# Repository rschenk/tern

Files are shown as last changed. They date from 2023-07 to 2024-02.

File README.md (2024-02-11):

# Tern

Terns are small white seabirds that can hover, but it's also a 30-key keyboard based on the [Hummingbird](https://github.com/PJE66/hummingbird)! Differences from the Hummigbird:

* Hot swappable
* Spaced for Chosfox CFX keycaps (tighter than normal choc spacing)
* Pinky keys are dropped down
* Thumbs are more reachy

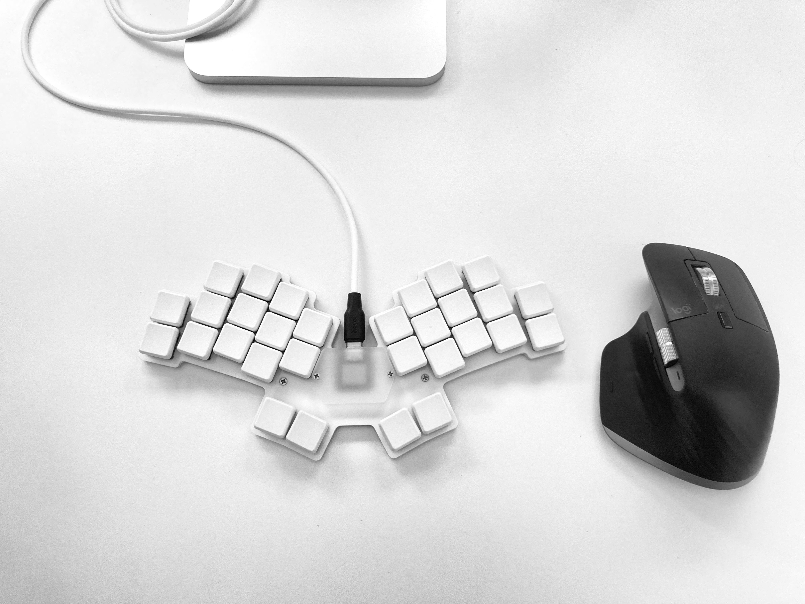
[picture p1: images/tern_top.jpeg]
tern_top


I much prefer reachy thumbs vs tucky thumbs. Years of wiping out on skateboards means my right thumb doesn’t really make that tucking motion anymore.

The other deviation from the hummingbird is that I’m using the upper pinky key as my homerow. I’m using my pinky column as home and bottom rows, not top and home rows like the hummingbird does. Cognitively I like the hummingbird’s solution better, but after cutting a stack of cardboard prototypes, I just had to admit to myself that my pinky does not enjoy extending upwards.

## Case

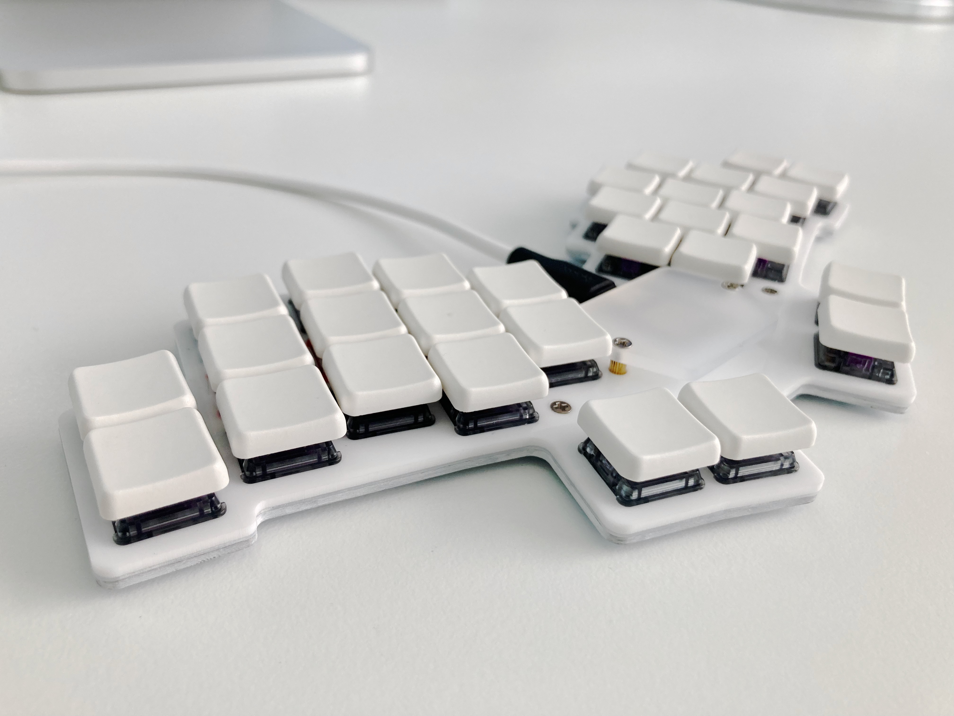
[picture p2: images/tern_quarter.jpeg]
tern_quarter


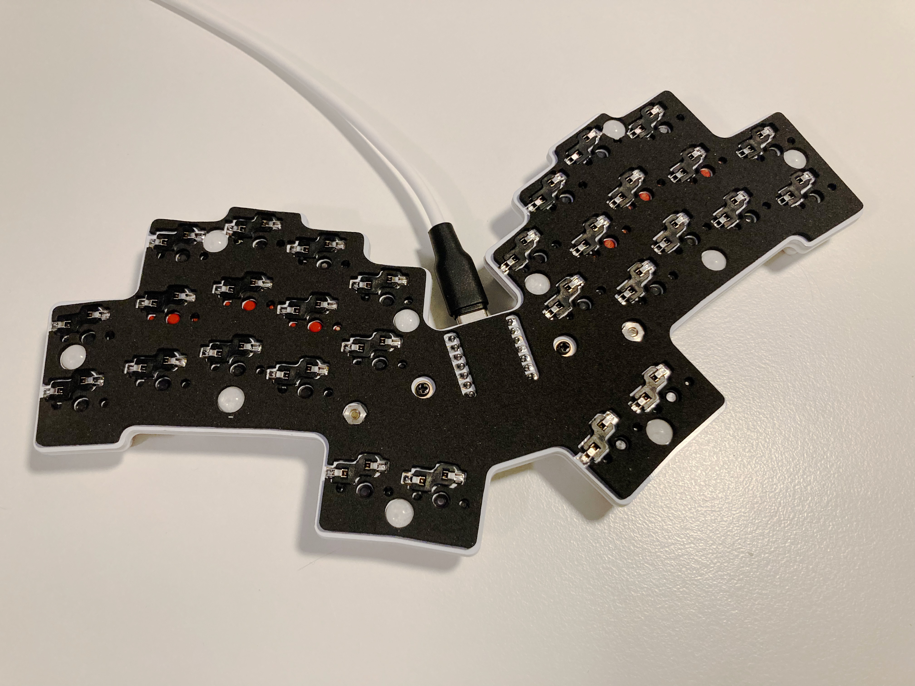
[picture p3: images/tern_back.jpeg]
tern_back


There are laser cutting files for a case in `case`. The switch plate is made from 1/16" acrylic, and there is a 0.6mm silicone gasket sitting between it and the PCB. I don't actually think the switchplate does anything functional but it looks more finished. There is a file for cutting a sheet of self-adhesive foam for the back which really helps to dampen the sound. I used 1mm sticky backed EVA. 

## Firmware

This uses an identical matrix to the Hummingbird, so you can just lie to your firmware and tell it that it's a Hummingbird. As I mentioned, though, since I dropped the pinkies and use them as home-bottom, using the stock Hummingbird config will make your keymap look a bit strange. I've included a config for ZMK in `firmware/zmk` that tweaks the matrix mapping to allow your keymap to reflect the actual position of the keys.

## Build Guide

[Build guide and bill of materials are here](docs/build_guide.md)

## Want Sculpted Keycaps?

I designed this board for Chosfox CFX keycaps, which are 1mm narrower than standard Choc keycaps such as MBK. The CFX keycaps are great if you like flat uniform keycaps, but if you want something sculpted, I forked the Chicago Steno repo and resized them to fit the CFX spacing. They are also sprued so you can 3D print them from someplace like JLC. See [rschenk/cfx_chicago_stenographer](https://github.com/rschenk/cfx_chicago_stenographer)

## Thanks

* [Hummingbird](https://github.com/PJE66/hummingbird) for the original idea and matrix
* [Rufous](https://github.com/jcmkk3/trochilidae) for the basis of the Ergogen config and routing

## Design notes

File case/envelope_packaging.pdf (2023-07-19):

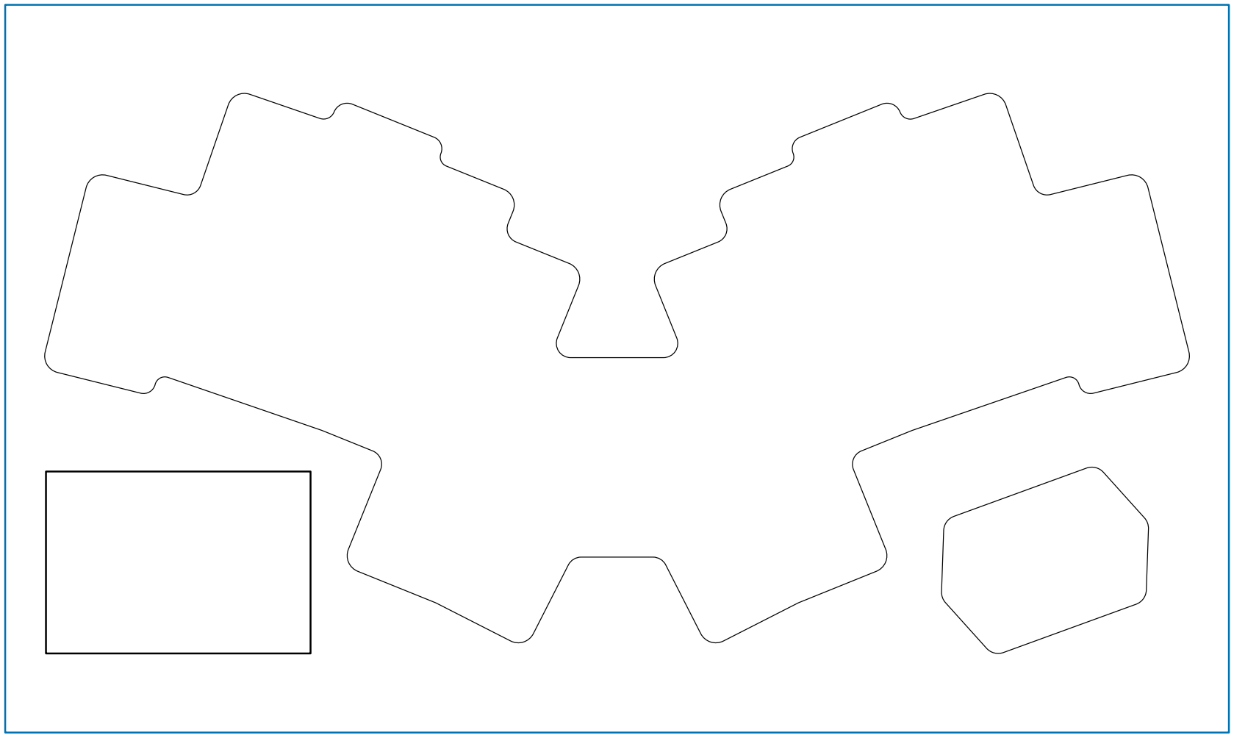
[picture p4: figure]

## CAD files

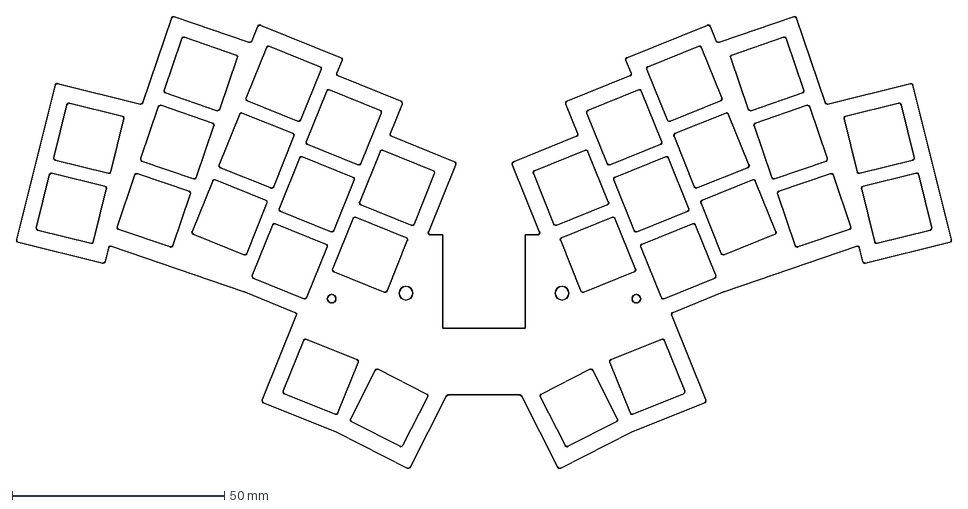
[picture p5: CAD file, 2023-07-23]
ergogen/output/outlines/switchplate.dxf
220.5 x 106.6 mm

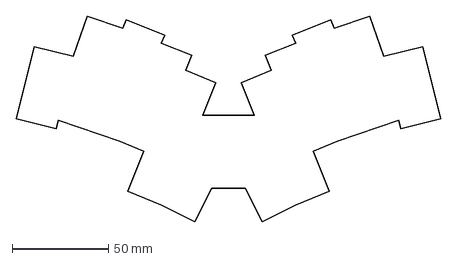
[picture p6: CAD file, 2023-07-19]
ergogen/output/outlines/panel.dxf
220.6 x 106.8 mm

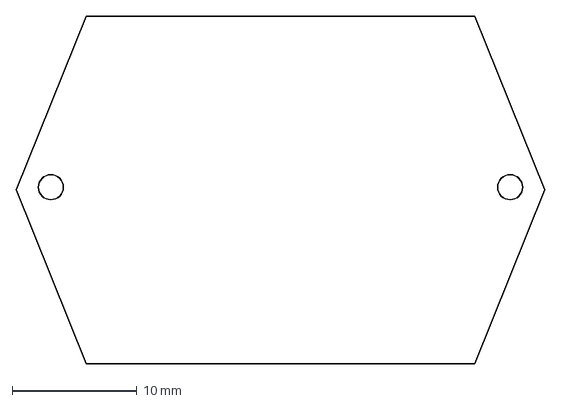
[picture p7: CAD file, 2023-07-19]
ergogen/output/outlines/mcu_cover.dxf
42.4 x 27.8 mm

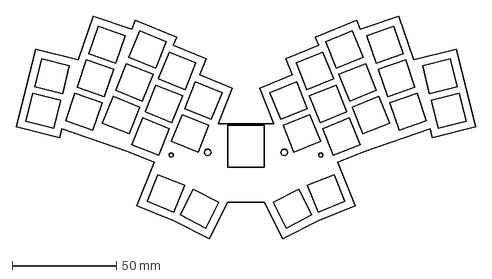
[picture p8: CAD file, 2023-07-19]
ergogen/output/outlines/demo_switches.dxf
220.6 x 106.8 mm

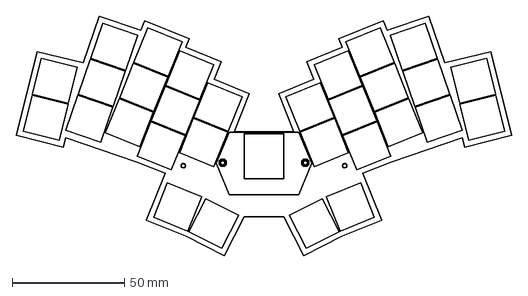
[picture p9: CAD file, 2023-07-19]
ergogen/output/outlines/demo_keycaps.dxf
220.6 x 106.8 mm

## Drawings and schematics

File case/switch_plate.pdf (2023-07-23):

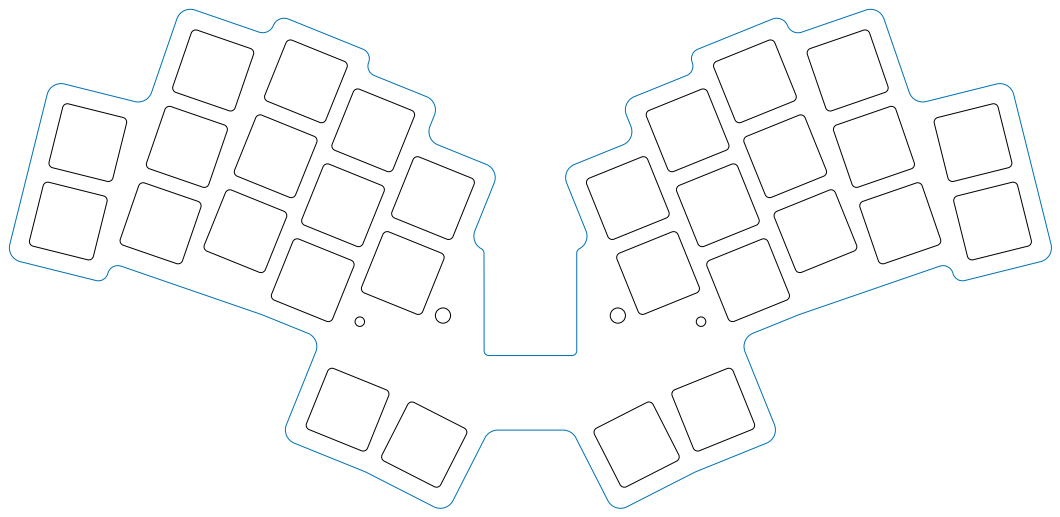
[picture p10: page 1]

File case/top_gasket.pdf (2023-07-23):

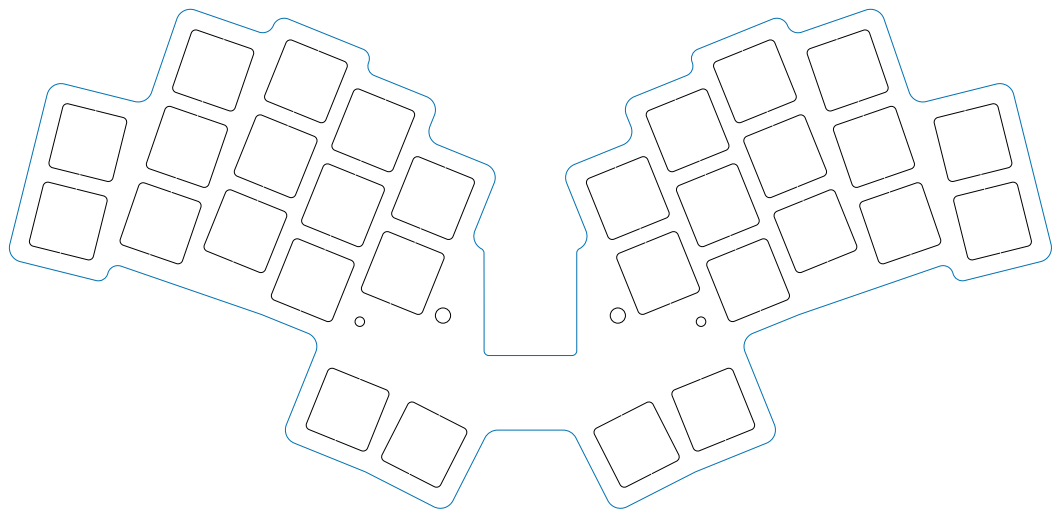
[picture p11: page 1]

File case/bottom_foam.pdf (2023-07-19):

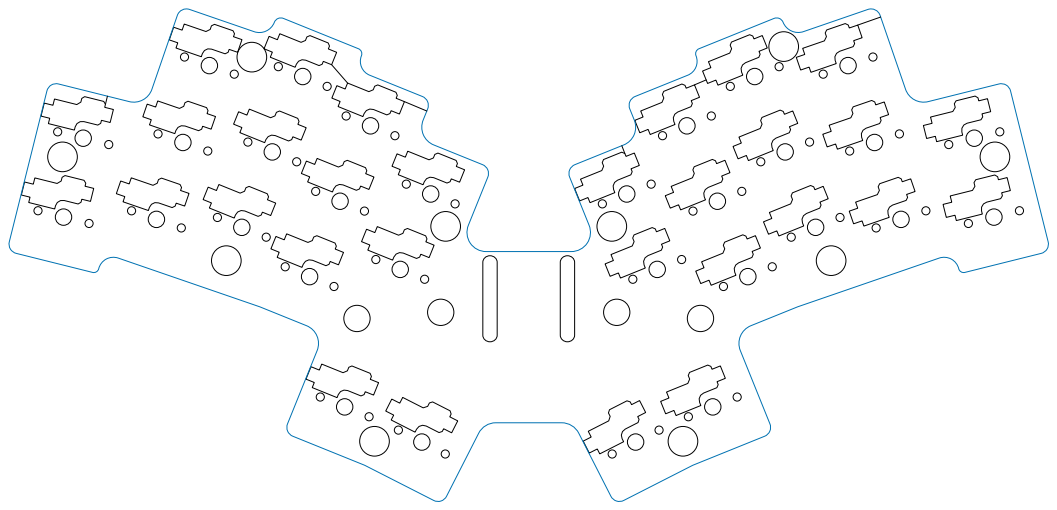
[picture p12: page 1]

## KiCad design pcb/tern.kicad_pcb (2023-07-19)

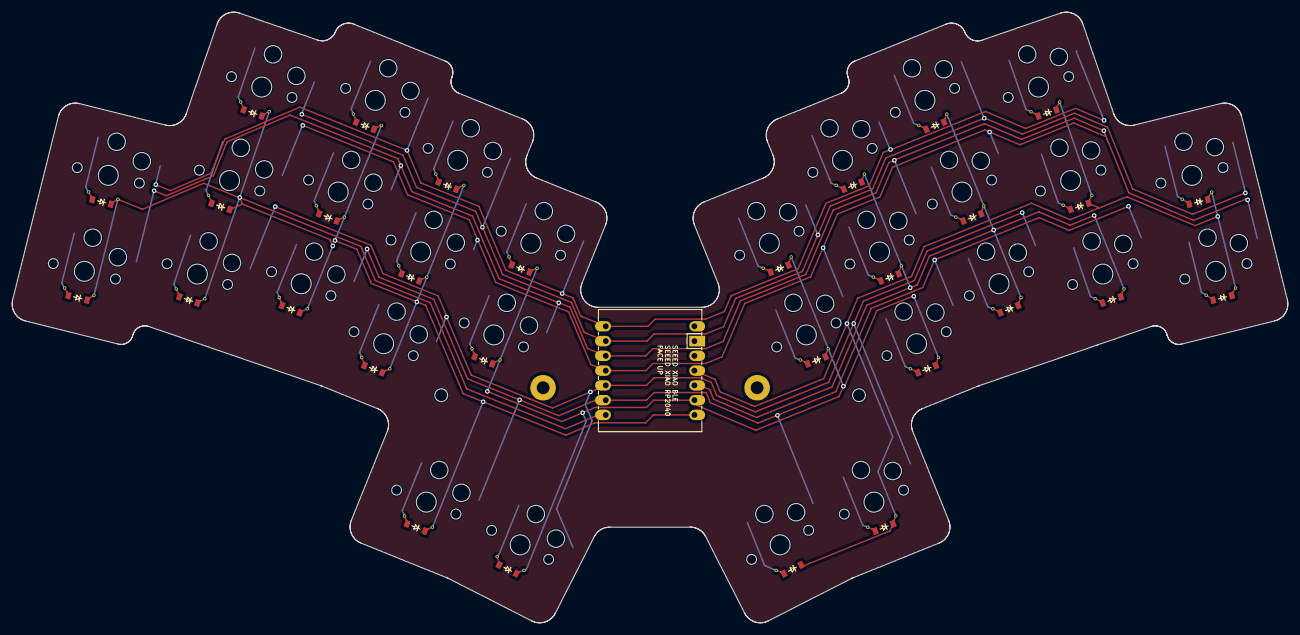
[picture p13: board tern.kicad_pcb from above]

Board: 2 copper layers, 219.3 x 105.0 mm, 95 parts (0 on the bottom side), 41 nets.

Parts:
D1, D2, D3, D4, D5, D6, D7, D8, D9, D10, D11, D12, D13, D14, D15, D16, D17, D18, D19, D20, D21, D22, D23, D24, D25, D26, D27, D28, D29, D30: ComboDiode
MCU1: xiao-ble
PAD1, PAD2: MountingHole_2.2mm_M2
PAD3, PAD4: MountingHole_2.2mm_M2_Pad
S1, S2, S3, S4, S5, S6, S7, S8, S9, S10, S11, S12, S13, S14, S15, S16, S17, S18, S19, S20, S21, S22, S23, S24, S25, S26, S27, S28, S29, S30: PG1350
SB1, SB2, SB3, SB4, SB5, SB6, SB7, SB8, SB9, SB10, SB11, SB12, SB13, SB14, SB15, SB16, SB17, SB18, SB19, SB20, SB21, SB22, SB23, SB24, SB25, SB26, SB27, SB28, SB29, SB30: ChocBonusGoodies

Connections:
P0: MCU1.1, S2.2, S8.2, S13.2, S18.2, S24.2
P1: MCU1.2, S5.2, S11.2, S15.2, S21.2, S26.2
P2: MCU1.3, S1.2, S7.2, S12.2, S17.2, S23.2
P3: MCU1.4, S4.2, S10.2, S14.2, S20.2, S25.2
P4: MCU1.5, S3.2, S9.2, S19.2, S28.2, S29.2
P5: MCU1.6, S6.2, S16.2, S22.2, S27.2, S30.2
P6: D1.1, D1.3, D1.4, D2.1, D2.3, D2.4, D3.1, D3.3, D3.4, D4.1, D5.1, D5.3, D5.4, D6.1, D6.3, D6.4, MCU1.7
P7: D7.1, D7.3, D7.4, D8.1, D8.3, D8.4, D9.1, D9.3, D9.4, D10.1, D10.3, D10.4, D11.1, D11.3, D11.4, D27.1, D27.3, D27.4, MCU1.8
P8: D12.1, D12.3, D12.4, D13.1, D13.3, D13.4, D22.1, D22.3, D22.4, D25.1, D25.3, D25.4, D26.1, D26.3, D26.4, D28.1, D28.3, D28.4, MCU1.9
P9: D16.1, D16.3, D16.4, D19.1, D19.3, D19.4, D20.1, D20.3, D20.4, D21.1, D21.3, D21.4, D23.1, D23.3, D23.4, D24.1, D24.3, D24.4, MCU1.10
P10: D14.1, D14.3, D14.4, D15.1, D15.3, D15.4, D17.1, D17.3, D17.4, D18.1, D18.3, D18.4, D29.1, D29.3, D29.4, D30.1, MCU1.11
index_bottom: D9.2, D9.6, D9.7, S9.1
index_home: D10.2, D10.6, D10.7, S10.1
index_top: D11.2, D11.6, D11.7, S11.1
inner_home: D12.2, D12.6, D12.7, S12.1
inner_top: D13.2, D13.6, D13.7, S13.1
middle_bottom: D6.2, D6.6, D6.7, S6.1
middle_home: D7.2, D7.6, D7.7, S7.1
middle_top: D8.2, D8.6, D8.7, S8.1
mirror_index_bottom: D22.2, D22.6, D22.7, S22.1
mirror_index_home: D23.2, D23.6, D23.7, S23.1
mirror_index_top: D24.2, D24.6, D24.7, S24.1
mirror_inner_home: D25.2, D25.6, D25.7, S25.1
mirror_inner_top: D26.2, D26.6, D26.7, S26.1
mirror_middle_bottom: D19.2, D19.6, D19.7, S19.1
mirror_middle_home: D20.2, D20.6, D20.7, S20.1
mirror_middle_top: D21.2, D21.6, D21.7, S21.1
mirror_pinky_home: D14.2, D14.6, D14.7, S14.1
mirror_pinky_top: D15.2, D15.6, D15.7, S15.1
mirror_reachy_default: D30.2, D30.6, D30.7, S30.1
mirror_ring_bottom: D16.2, D16.6, D16.7, S16.1
mirror_ring_home: D17.2, D17.6, D17.7, S17.1
mirror_ring_top: D18.2, D18.6, D18.7, S18.1
mirror_tucky_default: D29.2, D29.6, D29.7, S29.1
pinky_home: D1.2, D1.6, D1.7, S1.1
pinky_top: D2.2, D2.6, D2.7, S2.1
reachy_default: D28.2, D28.6, D28.7, S28.1
ring_bottom: D3.2, D3.6, D3.7, S3.1
ring_home: D4.2, D4.6, D4.7, S4.1
ring_top: D5.2, D5.6, D5.7, S5.1
tucky_default: D27.2, D27.6, D27.7, S27.1

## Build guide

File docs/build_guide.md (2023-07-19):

# Tern Build Guide

This is a very standard build, the only gotcha is that the key spacing is only for ChosFox CFX keycaps. MBK keycaps will not work, they're too wide.

## Parts List

### Required Parts

| Description | Quantity | Notes |
| --- | --- | --- |
| Tern PCB | 1 | See gerbers.zip |
| Seeed XIAO | 1 | You can use either the BLE version or the RP2040 version |
| Choc hotswap sockets | 30 | |
| 1N4148W Diodes | 30 | SOD-123 surface mount package |
| Choc v1 switches | 30 | |
| Chosfox CFX keycaps  | 30 | |

### Optional Parts

| Description | Quantity | Notes |
| --- | --- | --- |
| Controller sockets | 2 | Supports Mill Max sockets such as 315-43-114-41-001000 and also supports Peel-A-Way super duper low profile sockets |

### Case Parts

| Description | Quantity | Notes |
| --- | --- | --- |
| Top plate | 1 | 1/16" acrylic, see `case/switch_plate.pdf` |
| Top gasket | 1 | 0.6mm silicone sheet, such as silicone placemats from [Amazon](https://www.amazon.com/dp/B088LKLSTG), see `case/top_gasket.pdf` |
| Controller cover | 1 | 1/8" acrylic, see `case/mcu_cover.pdf` |
| Bottom foam | 1 | 1mm self-adhesive EVA foam |
| M2 6mm screws | 6 | Four for the controller cover, two for the top plate |
| M2 thin nuts | 2 | For the top plate |
| M2 8mm standoffs | 2 | For the controller cover |
| 6mm x 2mm bumper feet | 10 | |

## PCB Assembly

I assembled it in this order:

- Hotswap sockets
- Controller sockets
- Diodes

## Firmware

Electrically-speaking, this keyboard is a Hummingbird, so you can treat it just like the Hummingbird to compile your keymap. I know ZMK has Hummingbird support baked in, not sure about QMK (presumably it does too).

However, I use my pinky columns as "home-bottom" rather than the Hummingbird's "top-home." If you are like me, then your keymap will look a bit strange using the hummingbird's config because the pinky column will have to be shifted up one row in the keymap file. If this bothers you, then you can use the tern shield definition in this repo to correct that, so the location of the keys in your keymap will match their location in physical space. This config is literally identical to the Hummingbird config in the ZMK repo, except that I changed the mapping of the matrix in the overlay.

```shell
# Copy the contents of firmware/zmk to your zmk-config/config/boards/shields/tern
cp -R ./firmware/zmk /path-to/zmk-config/config/boards/shields/tern
# Copy the default keymap into your config directory to get started
cd /path-to/zmk-config/config
cp boards/shields/tern/tern.keymap .
touch tern.conf
```

## Case

### Laser Cutting

The case is optional and intended to be laser cut. The order of assembly should be as follows

- The switchplate is purely cosmetic but looks nice, and should be laser cut from 1/16" acrylic.
- Silicone gasket should be cut from 0.6mm silicone sheet, I use placemats from Amazon
- Controller cover can be cut from whatever you like, I use 1/8" acrylic
- Bottom foam should be cut from 1mm self-adhesive EVA foam. You can also use 2mm if you prefer but it will extend slightly below the hotswap sockets. When laser cutting, the adhesive side should be facing down.

## Assembly

1. Remove the switch holes from the silicone gasket. These are held in place by tiny little tabs to keep them from blowing around and getting into mischief during laser cutting. Just gently pop them off with your fingers.
2. Lay the gasket on the PCB
3. Place the switchplate on
4. Gently attach the switchplate to the PCB with a 6mm M2 screw and a low profile nut on the underside. If you are using the `v0.1` PCB, I forgot to metal plate these mounting holes on the PCB, so be gentle when you tighten this nut. (I'll fix this in `v1`.) It doesn't need to be super tight, it's really there just to register everything in the right place.
5. Install the switches. Sometimes the switch plate fitment can be a bit tight. Just go easy and they will all click in.
6. Install the controller cover
7. Flip it over, and carefully install the bottom foam. Use the hotswap sockets as a guide to register it in place.
8. Finally, install the 6mm x 2mm clear bumpon feet, using the bottom foam's circular cutouts to locate them.

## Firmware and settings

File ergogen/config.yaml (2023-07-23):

meta:
  engine: 4.0.0
  name: tern

units:
  # Parameters
  # ==========
  # For Chocfox CFX Keycaps
  capx: 16.5      # Key cap size horizontal
  capy: 16.5      # Key cap size vertical
  kx: capx + 0.5    # Key spacing horizontal
  ky: capy + 0.5    # Key spacing vertical
  angle: 22         # Angle between halves
  pinky_stagger: 5/4ky
  pinky_splay: 5  # Degrees of splay between pinky and ring columns
  pinky_adj: -3   # Adjustment to compensate for splay spacing
  ring_splay: 3
  ring_adj: -8

  # Constants
  # =========
  xiao_x: 17.5
  xiao_y: 20
  sf: 21.5        # Switch footprint (square)

  # Outlines
  # ========
  xiao_cutout_x: 19.5
  xiao_cutout_y: 22.5
  mounting_hole_r: 1
  clearance_hole_r: 1.6
  cover_hole_margin: 3  # Inset from the edge

  # Laser
  # -----
  kerf: 0.006 * 25.4 # Inches to mm

points:
  # Keys/Switches
  # =============
  zones.matrix:
    anchor.shift: [150, -125]
    rotate: -angle + pinky_splay + ring_splay
    mirror: &mirror
      ref: matrix_inner_top
      shift: [0.5sf, 0.5sf]
      distance: 13
    key: &key
      width: capx
      height: capy
      spread: kx
      padding: ky
      autobind: false
    rows:
      bottom:
      home:
      top:
    columns:
      pinky:
        rows:
          bottom.skip: true
          home:
            bind: [0.5ky, 0, 0, 0]
            row_net: P2
            column_net: P6
          top:
            bind: [0, 0.5kx, 0.5ky, 0]
            row_net: P0
            column_net: P6
          home.mirror:
            row_net: P3
            column_net: P10
          top.mirror:
            row_net: P1
            column_net: P10
      ring:
        key:
          stagger: pinky_stagger
          splay: -pinky_splay
          origin: [0, pinky_adj]
          spread: 1.1kx
        rows:
          bottom:
            bind: [0.5ky, 3kx, 0.5, 0.5kx]
            row_net: P4
            column_net: P6
          home:
            bind: [0, 0.5kx, 0, 0]
            row_net: P3
            column_net: P6
          top:
            bind: [0, 0.5kx, 0.5ky, 0]
            row_net: P1
            column_net: P6
          bottom.mirror:
            row_net: P5
            column_net: P9
          home.mirror:
            row_net: P2
            column_net: P10
          top.mirror:
            row_net: P0
            column_net: P10
      middle:
        key:
          stagger: 0.25ky
          splay: -ring_splay
          origin: [0, ring_adj]
        rows:
          bottom:
            bind: [0.5ky, 0.5kx, 0, 0.5kx]
            row_net: P5
            column_net: P6
          home:
            bind: [0, 0.5kx, 0, 0]
            row_net: P2
            column_net: P7
          top:
            bind: [0, 0, 0.5ky, 0]
            row_net: P0
            column_net: P7
          bottom.mirror:
            row_net: P4
            column_net: P9
          home.mirror:
            row_net: P3
            column_net: P9
          top.mirror:
            row_net: P1
            column_net: P9
      index:
        key:
          stagger: -0.25ky
        rows:
          bottom:
            bind: [0.5ky, 0, 0, 0]
            row_net: P4
            column_net: P7
          home:
            row_net: P3
            column_net: P7
          top:
            bind: [0, 0, 0.5ky, 0.5kx]
            row_net: P1
            column_net: P7
          bottom.mirror:
            row_net: P5
            column_net: P8
          home.mirror:
            row_net: P2
            column_net: P9
          top.mirror:
            row_net: P0
            column_net: P9
      inner:
        key:
          stagger: -0.5ky
        rows:
          bottom.skip: true
          home:
            bind: [0.5ky, 0, 0.5ky, 0.5kx]
            row_net: P2
            column_net: P8
            tags:
              matrix_inner: true
          top:
            bind: [0, 0, 0.5ky, 0.5kx]
            row_net: P0
            column_net: P8
            tags:
              matrix_inner: true
          home.mirror:
            row_net: P3
            column_net: P8
          top.mirror:
            row_net: P1
            column_net: P8
  zones.thumb:
    anchor:
      ref: matrix_inner_bottom
      shift: [0, -14]
    mirror: *mirror
    key: *key
    columns:
      tucky:
        key:
          name: thumb_tucky
          bind: [0.5ky, 0.5kx, 0, 0]
          row_net: P5
          column_net: P7
        key.mirror:
          row_net: P4
          column_net: P10
      reachy:
        key:
          stagger: 0
          splay: -5
          origin: [-kx/2, -kx/2]
          name: thumb_reachy
          bind: [1.5ky, 0, 0, 0]
          row_net: P4
          column_net: P8
        key.mirror:
          row_net: P5
          column_net: P10
  zones.mcu:
    anchor:
      aggregate.parts: [matrix_inner_top, mirror_matrix_inner_top]
      shift: [0, -0.7ky - 0.5xiao_y]
    key:
      name: mcu
      width: xiao_x
      height: xiao_y
  zones.mounting_hole:
    anchor:
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
